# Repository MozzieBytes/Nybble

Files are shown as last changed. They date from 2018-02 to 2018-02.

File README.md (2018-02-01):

# Nybble
Cherry MX, and Alps compatible 45-key mechanical keyboard

## Features:
  - QMK compatible ATMEGA32u4 microcontroller.
  - Per-key diodes for n-key rollover support.
  - Alps, and Cherry MX compatible switch footprints to allow for a wide range of supported switch types.
  
## TODO:
  - Add LED support to the pcb.
  - Budget-oriented option for PCB to allow use of Teensy 2.0 microcontroller to reduce costs of pcb production.
  - Add SVG files for laser-cut sandwich case.
  - Create default QMK Firmware configuration for plug-and-play functionality.
  - Add silkscreening to pcb

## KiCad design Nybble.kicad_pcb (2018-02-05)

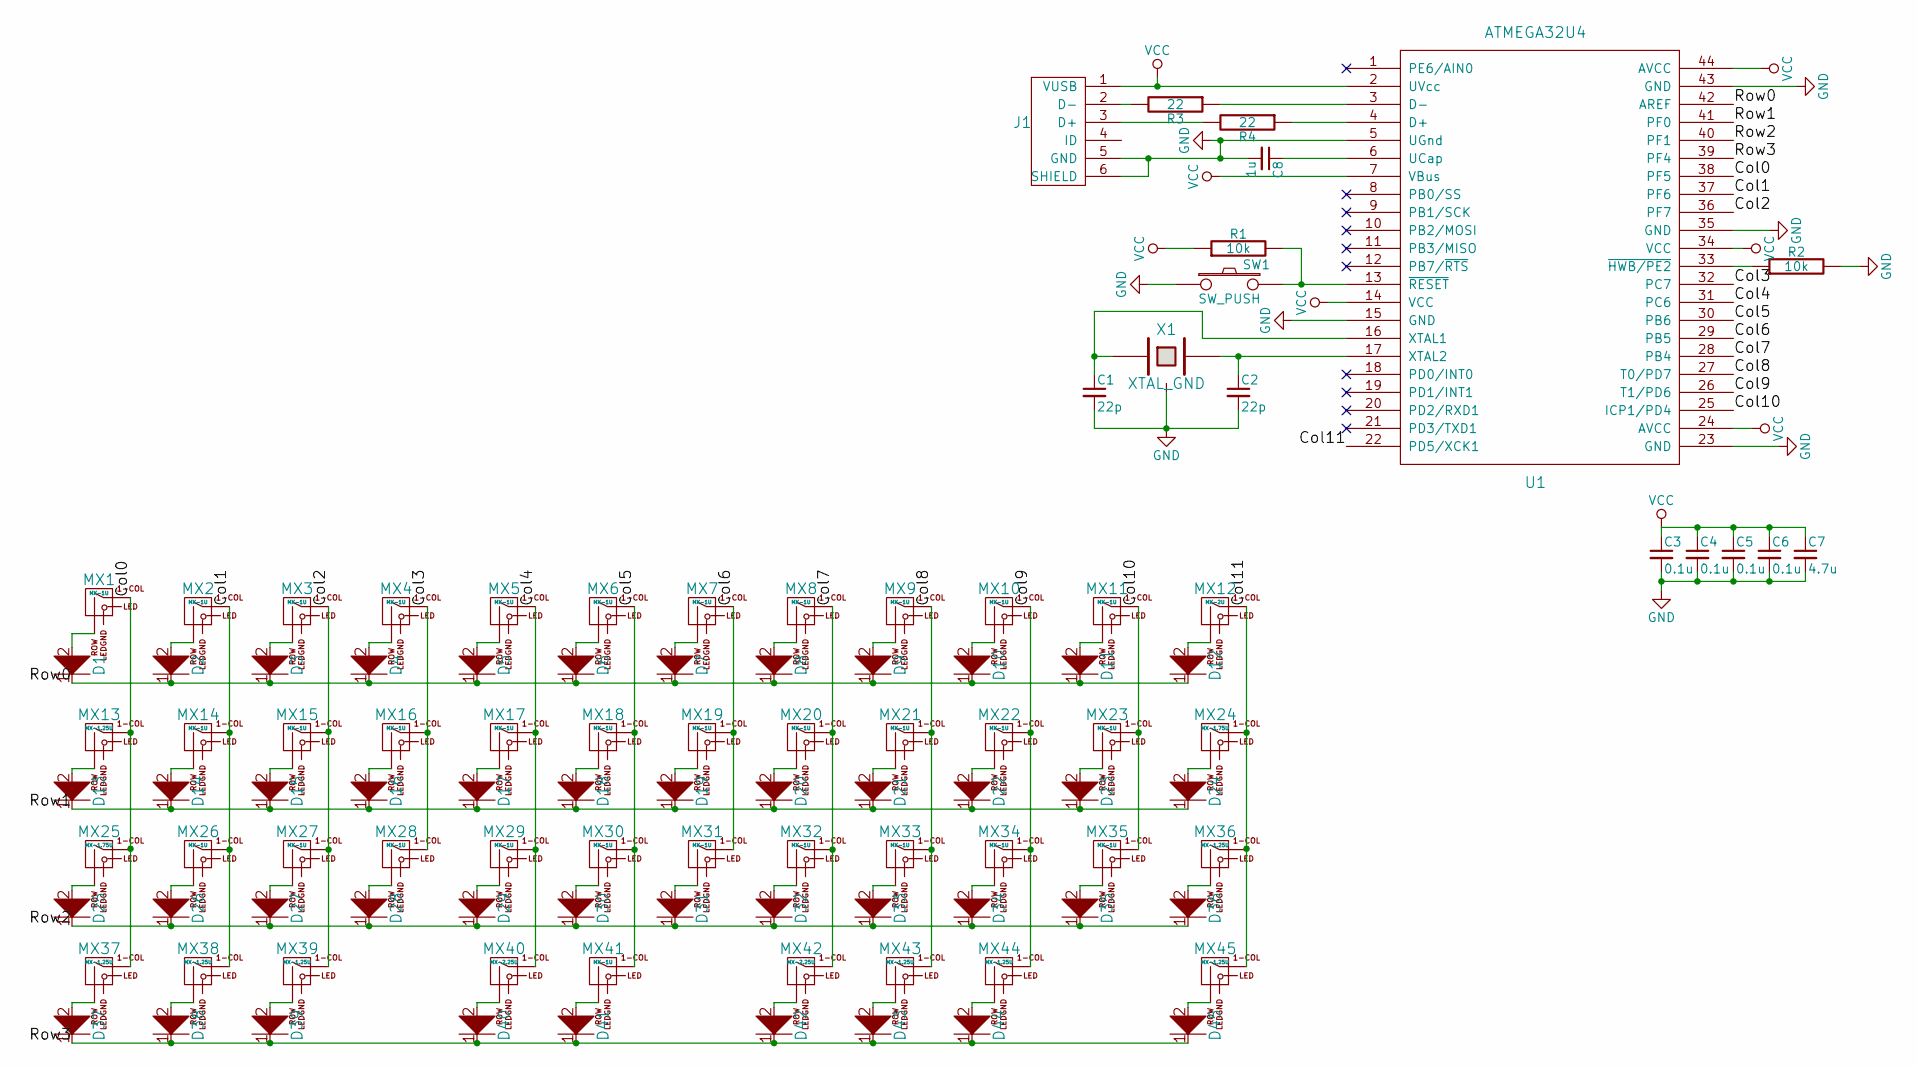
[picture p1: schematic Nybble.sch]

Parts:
C1, C2: 22p; C_0805_HandSoldering
C3, C4, C5, C6: 0.1u; C_0805_HandSoldering
C7: 4.7u; C_0805_HandSoldering
C8: 1u; C_0805_HandSoldering
D1, D2, D3, D4, D5, D6, D7, D8, D9, D10, D11, D12, D13, D14, D15, D16, D17, D18, D19, D20, D21, D22, D23, D24, D25, D26, D27, D28, D29, D30, D31, D32, D33, D34, D35, D36, D37, D38, D39, D40, D41, D42, D43, D44, D45: D; D_SOD123_axial
J1: USB_mini_micro_B; USB_miniB_hirose_5S8
MX1, MX2, MX3, MX4, MX5, MX6, MX7, MX8, MX9, MX10, MX11, MX14, MX15, MX16, MX17, MX18, MX19, MX20, MX21, MX22, MX23, MX26, MX27, MX28, MX29, MX30, MX31, MX32, MX33, MX34, MX35, MX41: MX-1U; MX-1U-NoLED
MX12: MX-2U; MX-2U-NoLED
MX13, MX36, MX37, MX38, MX39, MX43, MX44, MX45: MX-1.25U; MX-1.25U-NoLED
MX24, MX25: MX-1.75U; MX-1.75U-NoLED
MX40, MX42: MX-2.25U; MX-2.25U-NoLED
R1, R2: 10k; R_0805_HandSoldering
R3, R4: 22; R_0805_HandSoldering
SW1: SW_PUSH; SW_SPST_TL3342
U1: ATMEGA32U4; TQFP-44_10x10mm_Pitch0.8mm
X1: XTAL_GND; Crystal_SMD_3225-4pin_3.2x2.5mm

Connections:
/Col0: MX1.1 (COL), MX13.1 (COL), MX25.1 (COL), MX37.1 (COL), U1.38 (PF5)
/Col1: MX2.1 (COL), MX14.1 (COL), MX26.1 (COL), MX38.1 (COL), U1.37 (PF6)
/Col2: MX3.1 (COL), MX15.1 (COL), MX27.1 (COL), MX39.1 (COL), U1.36 (PF7)
/Col3: MX4.1 (COL), MX16.1 (COL), MX28.1 (COL), U1.32 (PC7)
/Col4: MX5.1 (COL), MX17.1 (COL), MX29.1 (COL), MX40.1 (COL), U1.31 (PC6)
/Col5: MX6.1 (COL), MX18.1 (COL), MX30.1 (COL), MX41.1 (COL), U1.30 (PB6)
/Col6: MX7.1 (COL), MX19.1 (COL), MX31.1 (COL), U1.29 (PB5)
/Col7: MX8.1 (COL), MX20.1 (COL), MX32.1 (COL), MX42.1 (COL), U1.28 (PB4)
/Col8: MX9.1 (COL), MX21.1 (COL), MX33.1 (COL), MX43.1 (COL), U1.27 (T0/PD7)
/Col9: MX10.1 (COL), MX22.1 (COL), MX34.1 (COL), MX44.1 (COL), U1.26 (T1/PD6)
/Col10: MX11.1 (COL), MX23.1 (COL), MX35.1 (COL), U1.25 (ICP1/PD4)
/Col11: MX12.1 (COL), MX24.1 (COL), MX36.1 (COL), MX45.1 (COL), U1.22 (PD5/XCK1)
/Row0: D1.1, D2.1, D3.1, D4.1, D5.1, D6.1, D7.1, D8.1, D9.1, D10.1, D11.1, D12.1, U1.42 (AREF)
/Row1: D13.1, D14.1, D15.1, D16.1, D17.1, D18.1, D19.1, D20.1, D21.1, D22.1, D23.1, D24.1, U1.41 (PF0)
/Row2: D25.1, D26.1, D27.1, D28.1, D29.1, D30.1, D31.1, D32.1, D33.1, D34.1, D35.1, D36.1, U1.40 (PF1)
/Row3: D37.1, D38.1, D39.1, D40.1, D41.1, D42.1, D43.1, D44.1, D45.1, U1.39 (PF4)
GND: C1.2, C2.2, C3.2, C4.2, C5.2, C6.2, C7.2, C8.2, J1.5 (GND), J1.6 (SHIELD), R2.2, SW1.1, U1.5 (UGnd), U1.15 (GND), U1.23 (GND), U1.35 (GND), U1.43 (GND), X1.3
unnamed: C1.1, U1.16 (XTAL1), X1.1
unnamed: C2.1, U1.17 (XTAL2), X1.2
unnamed: C8.1, U1.6 (UCap)
unnamed: D1.2, MX1.2 (ROW)
unnamed: D2.2, MX2.2 (ROW)
unnamed: D3.2, MX3.2 (ROW)
unnamed: D4.2, MX4.2 (ROW)
unnamed: D5.2, MX5.2 (ROW)
unnamed: D6.2, MX6.2 (ROW)
unnamed: D7.2, MX7.2 (ROW)
unnamed: D8.2, MX8.2 (ROW)
unnamed: D9.2, MX9.2 (ROW)
unnamed: D10.2, MX10.2 (ROW)
unnamed: D11.2, MX11.2 (ROW)
unnamed: D12.2, MX12.2 (ROW)
unnamed: D13.2, MX13.2 (ROW)
unnamed: D14.2, MX14.2 (ROW)
unnamed: D15.2, MX15.2 (ROW)
unnamed: D16.2, MX16.2 (ROW)
unnamed: D17.2, MX17.2 (ROW)
unnamed: D18.2, MX18.2 (ROW)
unnamed: D19.2, MX19.2 (ROW)
unnamed: D20.2, MX20.2 (ROW)
unnamed: D21.2, MX21.2 (ROW)
unnamed: D22.2, MX22.2 (ROW)
unnamed: D23.2, MX23.2 (ROW)
unnamed: D24.2, MX24.2 (ROW)
unnamed: D25.2, MX25.2 (ROW)
unnamed: D26.2, MX26.2 (ROW)
unnamed: D27.2, MX27.2 (ROW)
unnamed: D28.2, MX28.2 (ROW)
unnamed: D29.2, MX29.2 (ROW)
unnamed: D30.2, MX30.2 (ROW)
unnamed: D31.2, MX31.2 (ROW)
unnamed: D32.2, MX32.2 (ROW)
unnamed: D33.2, MX33.2 (ROW)
unnamed: D34.2, MX34.2 (ROW)
unnamed: D35.2, MX35.2 (ROW)
unnamed: D36.2, MX36.2 (ROW)
unnamed: D37.2, MX37.2 (ROW)
unnamed: D38.2, MX38.2 (ROW)
unnamed: D39.2, MX39.2 (ROW)
unnamed: D40.2, MX40.2 (ROW)
unnamed: D41.2, MX41.2 (ROW)
unnamed: D42.2, MX42.2 (ROW)
unnamed: D43.2, MX43.2 (ROW)
unnamed: D44.2, MX44.2 (ROW)
unnamed: D45.2, MX45.2 (ROW)
unnamed: J1.2 (D-), R3.2
unnamed: J1.3 (D+), R4.2
unnamed: R1.2, SW1.2, U1.13 (~RESET)
unnamed: R2.1, U1.33 (~HWB/PE2)
unnamed: R3.1, U1.3 (D-)
unnamed: R4.1, U1.4 (D+)
VCC: C3.1, C4.1, C5.1, C6.1, C7.1, J1.1 (VUSB), R1.1, U1.2 (UVcc), U1.7 (VBus), U1.14 (VCC), U1.24 (AVCC), U1.34 (VCC), U1.44 (AVCC)

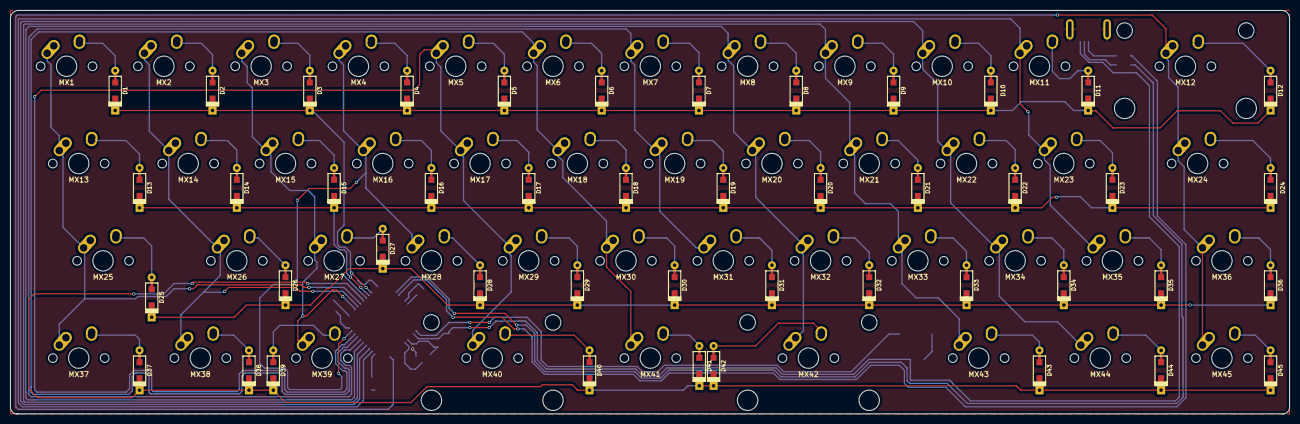
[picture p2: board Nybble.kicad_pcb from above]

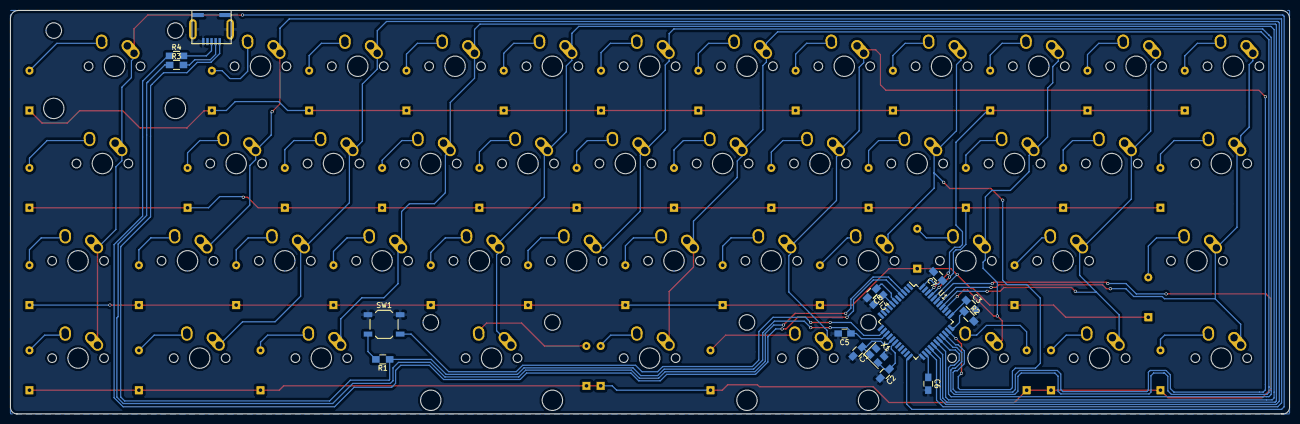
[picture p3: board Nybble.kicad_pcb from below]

Board: 2 copper layers, 250.4 x 79.0 mm, 106 parts (16 on the bottom side), 72 nets.

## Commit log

2018-01-26 Implemented gitignore from https://github.com/github/gitignore/blob/master/KiCad.gitignore
2018-01-26 Initial Commit, half completed PCB
    [Nybble.kicad_pcb, Nybble.sch]
2018-01-26 Finished the Switch Matrix -- May need to fix the labels
    [Nybble.sch]
2018-01-28 I screwed with a tonne of footprints, and attempted to generate a netlist, currently untested
    [Nybble.sch]
2018-01-28 Fixed issues in row connection
    [Nybble.sch]
2018-01-28 Moving all the controller smd components around the pcb
    [Nybble.kicad_pcb]
2018-01-28 Got a draft of the component layout
    [Nybble.kicad_pcb]
2018-01-28 Made a few fine edits to the controller
    [Nybble.kicad_pcb]
2018-01-28 Created PCB edge
    [Nybble.kicad_pcb]
2018-01-28 Added Ground zones
    [Nybble.kicad_pcb]
2018-01-28 Filled Ground Zones
    [Nybble.kicad_pcb]
2018-01-28 Fixed issues with the diode on switch 27
    [Nybble.sch]
2018-01-28 Starting to add traces to keyboard
    [Nybble.kicad_pcb]
2018-01-29 Fixed reset switch, and added a via between the two ground planes
    [Nybble.kicad_pcb]
2018-01-29 Fixed issues with the schematic
    [Nybble.sch]
2018-01-29 Finished the traces between the switches and the diodes
    [Nybble.kicad_pcb]
2018-01-29 Finished Wiring COlumns
    [Nybble.kicad_pcb]
2018-01-29 Finished routing the connections for the rows
    [Nybble.kicad_pcb]
2018-01-29 Fixed issues with row, and column traces
    [Nybble.kicad_pcb]
2018-01-29 Fixed issues with the netlist
    [Nybble.sch]
2018-01-29 Started rerouting everything on the pcb. I made so many silly mistakes
    [Nybble.kicad_pcb]
2018-01-29 Just about to leave class
    [Nybble.kicad_pcb]
2018-01-30 5 traces to go
    [Nybble.kicad_pcb]
2018-01-30 Finished pcb traces
    [Nybble.kicad_pcb]
2018-02-05 Fixed a few traces that were breaking the ground plane
    [Nybble.kicad_pcb]
2018-02-05 Fixed the traces by switch 37
    [Nybble.kicad_pcb]
